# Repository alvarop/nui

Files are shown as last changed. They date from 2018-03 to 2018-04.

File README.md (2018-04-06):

# Nui

## Overview

Nui is an IR(evntually also BLE) controlled volume controller for analog audio. It sits between your audio source and speakers and can amplify or reduce the volume using IR commands (and evntually BLE).

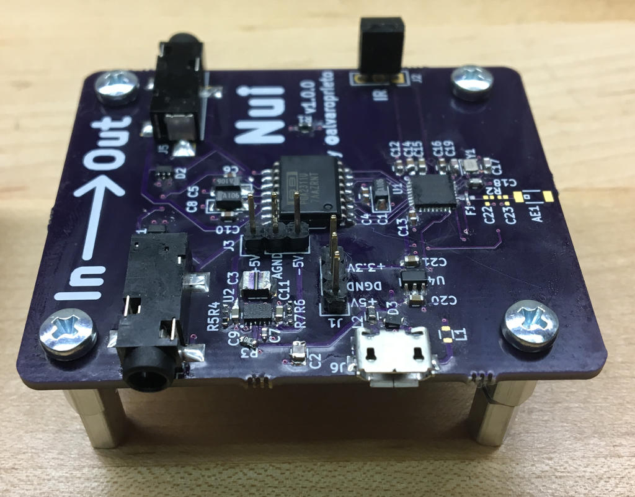
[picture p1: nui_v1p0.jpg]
Nui v1.0


Why do I need this, you may ask?

It all started because I have my trusty Logitech Z-2300 speakers and subwoofer I purchased back arond 2004/5. They still work great, but instead of being on my computer, they are used for my TV. Unfortunately, the TV's line out doesn't honor the TV's volume and is always outputting at max volume. Sure, I can get up and change the volume on the speakers themselves, but wouldn't it be more convenient to do it with the TV remote?!

That's how the Nui project started. It sits between my TV and my speakers and now I don't have to get up to change the volume :D

## Version 0.0.1 (Teensy version)

### Hardware
* The board files can be found [here](https://github.com/alvarop/nui/releases/tag/releases%2Fhw%2Fv0.0.1)

### Firmware
* The arduino/teensy code can be found [here](fw/teensy/nui.ino)

## Version 1.0.0 (NRF52 version)

### Hardware
* The board files can be found [here](hw/)

### Firmware
* The NRF52 code can be found [here](fw/nui/)

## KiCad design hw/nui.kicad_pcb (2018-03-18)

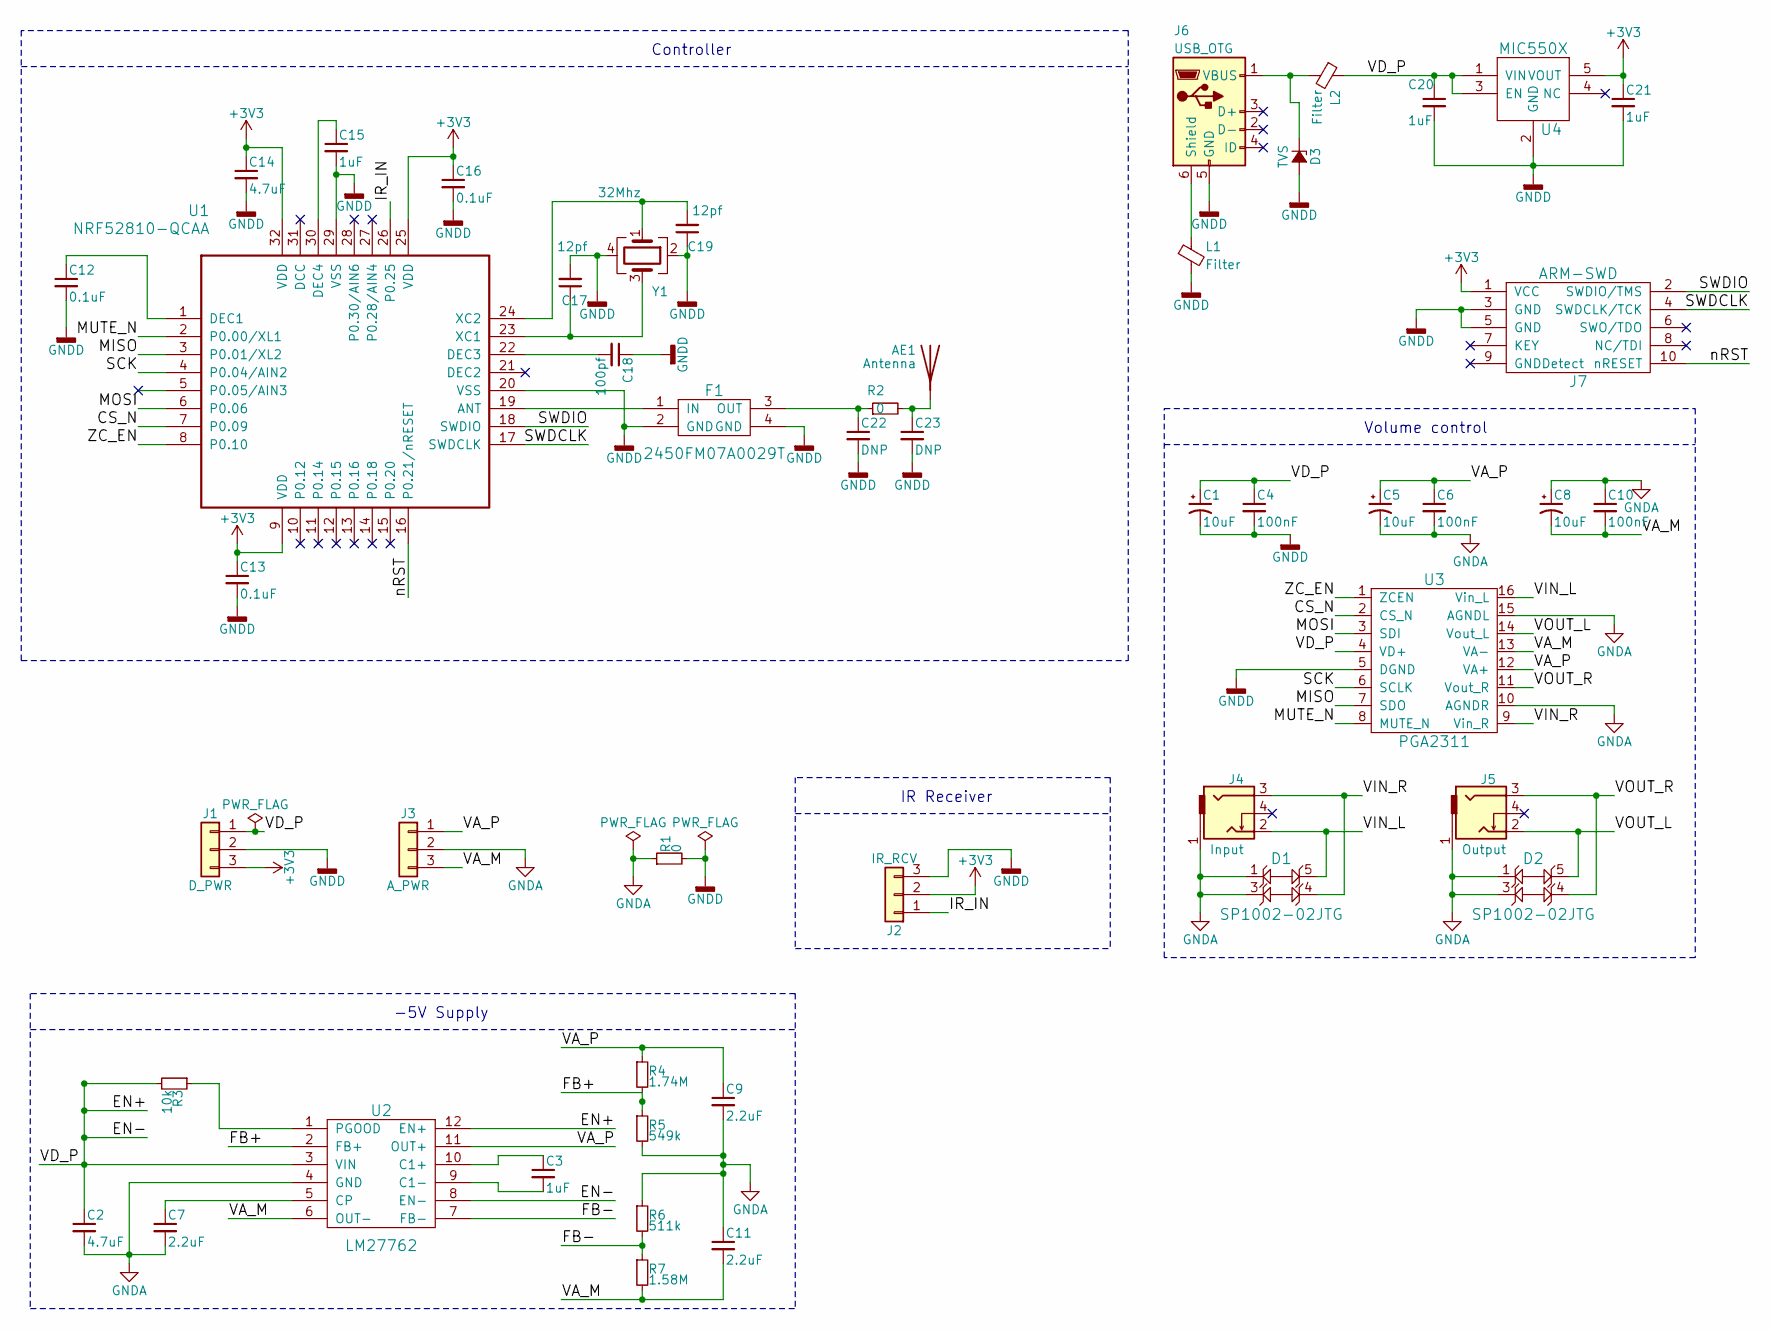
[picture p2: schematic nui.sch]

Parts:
AE1: Antenna; AMCA31-2R450G-S1F-T3
C1, C5, C8: 10uF; CP_Tantalum_Case-A_EIA-3216-18_Reflow; MPN F931A106MAA
C2: 4.7uF; C_0805; MPN LMK212BJ475KD-T
C3: 1uF; C_1210; MPN ECP-U1C105MA5
C4, C6, C10: 100nF; C_0603; MPN GRM188R71C104KA01D
C7: 2.2uF; C_0402_NoSilk; MPN JMK105BJ225MV-F
C9, C11: 2.2uF; C_0603; MPN C0603C225K8PACTU
C12, C13, C16: 0.1uF; C_0603
C14: 4.7uF; C_0603
C15, C20, C21: 1uF; C_0603
C17, C19: 12pf; C_0603
C18: 100pf; C_0603
C22, C23: DNP; C_0402_NoSilk
D1, D2: SP1002-02JTG; MPN SP1002-02JTG
D3: TVS; D_0603; MPN ESDA7P120-1U1M
F1: 2450FM07A0029T
J1: D_PWR; Pin_Header_Straight_1x03
J2: IR_RCV; Pin_Header_Straight_1x03; MPN TSOP2138
J3: A_PWR; Pin_Header_Straight_1x03
J4: Input; SJ-3524-SMT-TR; MPN SJ-3524-SMT-TR
J5: Output; SJ-3524-SMT-TR; MPN SJ-3524-SMT-TR
J6: USB_OTG; USB_MICRO_B
J7: ARM-SWD; ARM_SWD_SMD
L1, L2: Filter; R_0603; MPN BLM18KG221SZ1D
R1: 0; R_0603
R2: 0; R_0402_NoSilk
R3: 10k; R_0402_NoSilk; MPN CRCW040210K0JNEDC
R4: 1.74M; R_0402_NoSilk; MPN CRCW04021M74FKED
R5: 549k; R_0402_NoSilk; MPN CRCW0402549KFKED
R6: 511k; R_0402_NoSilk; MPN CRCW0402511KFKED
R7: 1.58M; R_0402_NoSilk; MPN CRCW04021M58FKED
U1: NRF52810-QCAA; NRF52810_QCAA_QFN32
U2: LM27762; MPN LM27762DSST
U3: PGA2311; PGA2311-SOIC; MPN PGA2311U
U4: MIC550X; SOT-23(M5)
Y1: 32Mhz; Crystal_SMD_2016-4pin_2.0x1.6mm

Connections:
+3V3: C13.1, C14.1, C16.1, C21.1, J1.3, J2.2, J7.1 (VCC), U1.9 (VDD), U1.25 (VDD), U1.32 (VDD), U4.5 (VOUT)
/CS_N: U1.7 (P0.09), U3.2 (CS_N)
/EN+: C1.1, C2.1, C4.1, C20.1, J1.1, L2.1, R3.2, U2.3 (VIN), U2.8 (EN-), U2.12 (EN+), U3.4 (VD+), U4.1 (VIN), U4.3 (EN)
/FB+: R4.2, R5.1, U2.2 (FB+)
/FB-: R6.2, R7.1, U2.7 (FB-)
/IR_IN: J2.1, U1.26 (P0.25)
/MISO: U1.3 (P0.01/XL2), U3.7 (SDO)
/MOSI: U1.6 (P0.06), U3.3 (SDI)
/MUTE_N: U1.2 (P0.00/XL1), U3.8 (MUTE_N)
/SCK: U1.4 (P0.04/AIN2), U3.6 (SCLK)
/SWDCLK: J7.4 (SWDCLK/TCK), U1.17 (SWDCLK)
/SWDIO: J7.2 (SWDIO/TMS), U1.18 (SWDIO)
/VA_M: C8.2, C10.2, C11.2, J3.3, R7.2, U2.6 (OUT-), U3.13 (VA-)
/VA_P: C5.1, C6.1, C9.1, J3.1, R4.1, U2.11 (OUT+), U3.12 (VA+)
/VIN_L: D1.5, J4.2, U3.16 (Vin_L)
/VIN_R: D1.4, J4.3, U3.9 (Vin_R)
/VOUT_L: D2.5, J5.2, U3.14 (Vout_L)
/VOUT_R: D2.4, J5.3, U3.11 (Vout_R)
/ZC_EN: U1.8 (P0.10), U3.1 (ZCEN)
/nRST: J7.10 (nRESET), U1.16 (P0.21/nRESET)
GNDA: C2.2, C5.2, C6.2, C7.2, C8.1, C9.2, C10.1, C11.1, D1.1, D1.3, D2.1, D2.3, J3.2, J4.1, J5.1, R1.1, R5.2, R6.1, U2.4 (GND), U3.10 (AGNDR), U3.15 (AGNDL)
GNDD: C1.2, C4.2, C12.2, C13.2, C14.2, C15.2, C16.2, C17.2, C18.1, C19.1, C20.2, C21.2, C22.2, C23.2, D3.2 (A), F1.2 (GND), F1.4 (GND), J1.2, J2.3, J6.5 (GND), J7.3 (GND), J7.5 (GND), L1.2, R1.2, U1.20 (VSS), U1.29 (VSS), U3.5 (DGND), U4.2 (GND), Y1.2, Y1.4
unnamed: AE1.1, C23.1, R2.2
unnamed: C3.1, U2.10 (C1+)
unnamed: C3.2, U2.9 (C1-)
unnamed: C7.1, U2.5 (CP)
unnamed: C12.1, U1.1 (DEC1)
unnamed: C15.1, U1.30 (DEC4)
unnamed: C17.1, U1.23 (XC1), Y1.3
unnamed: C18.2, U1.22 (DEC3)
unnamed: C19.2, U1.24 (XC2), Y1.1
unnamed: C22.1, F1.3 (OUT), R2.1
unnamed: D3.1 (K), J6.1 (VBUS), L2.2
unnamed: F1.1 (IN), U1.19 (ANT)
unnamed: J6.6 (Shield), L1.1
unnamed: R3.1, U2.1 (PGOOD)

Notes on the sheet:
Volume control
-5V Supply
Controller
IR Receiver

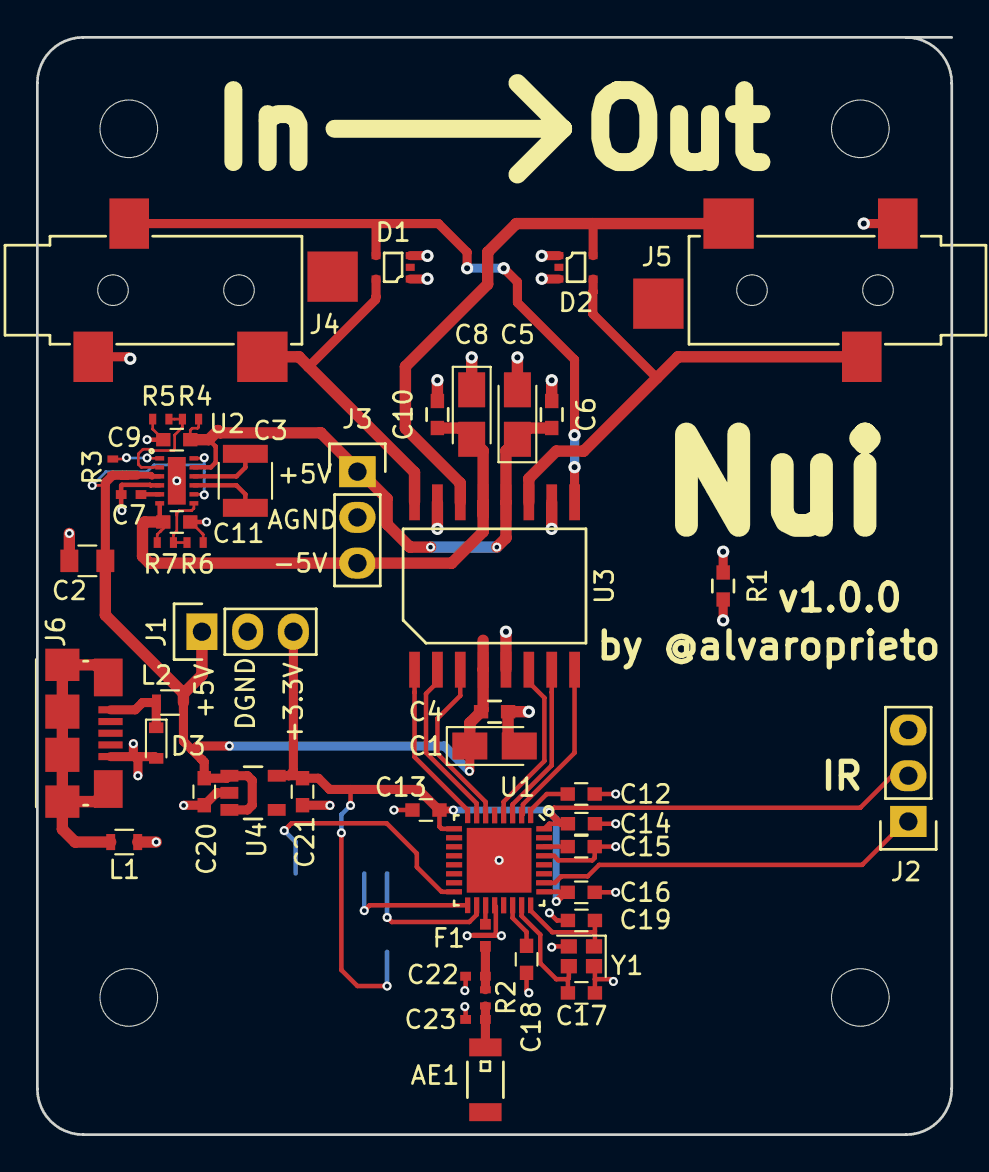
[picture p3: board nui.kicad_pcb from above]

Board: 2 copper layers, 50.8 x 61.0 mm, 49 parts (1 on the bottom side), 36 nets.

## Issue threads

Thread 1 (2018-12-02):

I have the same needs! Is this for sale?

trentrand, 2018-12-02:
Hey 👋

Great project! I attempted a similar solution by cracking open the speaker and replacing the potentiometer with an Arduino and a MCP41100 digital potentiometer.
The project produced horrible static and output quality; not sure why.

Anyways, this looks like a smarter solution which I'd love to have.

Do you have one for sale?

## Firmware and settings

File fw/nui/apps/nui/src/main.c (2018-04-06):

#include <assert.h>
#include <string.h>
#include <stdbool.h>

#include "sysinit/sysinit.h"
#include "console/console.h"
#include "os/os.h"
#include "bsp/bsp.h"
#include "hal/hal_gpio.h"
#include "hal/hal_timer.h"
#include "hal/hal_spi.h"

#include "nrfx.h"
#include "nrfx_spim.h"

#define NUI_TASK_PRI         (10)
#define NUI_STACK_SIZE       (256)
struct os_task nui_task;
os_stack_t nui_task_stack[NUI_STACK_SIZE];

typedef struct {
    uint32_t time;
    uint8_t value;
} edge_t;

static nrfx_spim_t spi_dev = NRFX_SPIM_INSTANCE(0);
static uint8_t current_volume = 164;
static bool mute = false;

// Maximum number of pulse edges to store
#define MAX_EDGES 128

// Timeout (in microseconds) before processing incoming data
#define TIMEOUT_US 11000

static edge_t edges[MAX_EDGES];
static uint16_t edge_index;

struct hal_timer ir_timeout_timer;

static struct os_mutex ir_processing_mutex;

static void ir_irq(void *arg) {
    os_error_t err;

    // If we're currently processing a packet, ignore incoming data
    // Not an issue now, but maybe once BLE is going it could cause problems
    err = os_mutex_pend(&ir_processing_mutex, 0);
    if(err == OS_OK) {
        // Store edge timestamp and current value
        edges[edge_index].time = hal_timer_read(1);
        edges[edge_index].value = hal_gpio_read(IR_IN_PIN);

        edge_index++;

        err = os_mutex_release(&ir_processing_mutex);
        assert(err == OS_OK);

        // Re-set ir timeout
        hal_timer_stop(&ir_timeout_timer);
        hal_timer_start(&ir_timeout_timer, TIMEOUT_US);
    }

}

// NEC Decoding state machine states
typedef enum {
    LEADING_PULSE,
    LEADING_SPACE,
    BIT_PULSE,
    BIT_SPACE,
} decode_state_t;

// Helper functions to determine if a pulse meets certain criteria
static inline bool is_leading_pulse(int32_t duration, uint8_t value) {
    return (value == 1 && duration > 8000 && duration < 10000);
}

static inline bool is_leading_space(int32_t duration, uint8_t value) {
    return (value == 0 && duration > 3500 && duration < 5500);
}

static inline bool is_bit_pulse(int32_t duration, uint8_t value) {
    return (value == 1 && duration > 400 && duration < 700);
}

static inline bool is_bit_space_0(int32_t duration, uint8_t value) {
    return (value == 0 && duration > 400 && duration < 700);
}

static inline bool is_bit_space_1(int32_t duration, uint8_t value) {
    return (value == 0 && duration > 1400 && duration < 1900);
}

// State machine to decode "NEC" IR encoded data
// See:
// http://techdocs.altium.com/display/FPGA/NEC+Infrared+Transmission+Protocol
uint16_t decode(uint32_t *result) {
    decode_state_t state = LEADING_PULSE;
    bool decoding = true;
    uint32_t index = 1;

    assert(result != NULL);

    *result = 0;

    while (decoding && index < edge_index) {
        int32_t duration = edges[index].time - edges[index - 1].time;
        uint8_t value = edges[index].value;
        switch(state) {
            case LEADING_PULSE: {
                if(is_leading_pulse(duration, value)) {
                    state = LEADING_SPACE;
                    index++;
                } else {
                    decoding = false;
                }
                break;
            }

            case LEADING_SPACE: {
                if(is_leading_space(duration, value)) {
                    state = BIT_PULSE;
                    index++;
                } else {
                    decoding = false;
                }
                break;
            }

            case BIT_PULSE: {
                if(is_bit_pulse(duration, value)) {
                    state = BIT_SPACE;
                    index++;
                } else {
                    decoding = false;
                }

                break;
            }

            case BIT_SPACE: {
                if(is_bit_space_0(duration, value)) {
                    (*result) <<= 1;
                    state = BIT_PULSE;
                    index++;
                } else if(is_bit_space_1(duration, value)) {
                    (*result) <<= 1;
                    (*result) |= 1;
                    state = BIT_PULSE;
                    index++;
                } else {
                    decoding=false;
                }

                break;
            }
        }
    }

    // Return the total number of edges (could be useful for repeat code, etc)
    return edge_index;
}

// These are the IR codes for the "AUX" setting on my particular Toshiba remote
typedef enum {
  AUX_VOL_DOWN = 0x4BB6C03F,
  AUX_VOL_UP = 0x4BB640BF,
  AUX_MUTE = 0x4BB6A05F
} commands_t;

void set_volume(uint8_t volume) {
    uint8_t vol[2] = {volume, volume};
    nrfx_spim_xfer_desc_t xfer = NRFX_SPIM_XFER_TX(&vol, sizeof(vol));
    hal_gpio_write(CS_N_PIN, 0);
    // hal_spi_txrx(0, vol, NULL, sizeof(vol));
    nrfx_spim_xfer(&spi_dev, &xfer, 0);
    hal_gpio_write(CS_N_PIN, 1);

    console_printf("volume %d\n", volume);
}

// Do something with the received data
static void process_ir_command(uint32_t command, uint16_t num_edges) {
    switch (command) {
        case AUX_VOL_DOWN: {
            console_printf("Volume down!\n");
            if (current_volume > 0) {
                current_volume--;
            }
            set_volume(current_volume);
            break;
        }
        case AUX_VOL_UP: {
            console_printf("Volume up!\n");
            if (current_volume < 255) {
                current_volume++;
            }
            set_volume(current_volume);
            break;
        }
        case AUX_MUTE: {
            console_printf("Mute!\n");
            mute = !mute;
            if(mute) {
                set_volume(0);
            } else {
                set_volume(current_volume);
            }
            break;
        }
        default: {
            // Do something with other codes?
            // console_printf("%08lX - %d\n", command, num_edges);
        }
    }
}

// Called to process data after not receiving IR edges for <TIMEOUT_US>
static void ir_timeout_cb(void *arg) {
    uint32_t result;
    uint16_t num_edges;
    os_error_t err;

    // Make sure we don't process more IR edges while we decode the packet
    err = os_mutex_pend(&ir_processing_mutex, 0xFFFFFFFF);
    assert(err == OS_OK);

    num_edges = decode(&result);

    // Reset edge index so we can receive the next packet!
    edge_index = 0;

    // Let the IR irq do it's thing again
    err = os_mutex_release(&ir_processing_mutex);
    assert(err == OS_OK);

    // Do something with the received data!
    process_ir_command(result, num_edges);
}

void nui_task_func(void *arg) {

    os_error_t err;

    // Use this mutex to make sure IR data isn't corrupted mid-decoding
    err = os_mutex_init(&ir_processing_mutex);
    assert(err == OS_OK);

    hal_gpio_irq_init(IR_IN_PIN, ir_irq, NULL,
        HAL_GPIO_TRIG_BOTH, HAL_GPIO_PULL_NONE);

    // Variable used to keep track of current pulse edge
    edge_index = 0;

    // 1MHz timer to measure incoming pulse edge times
    hal_timer_config(1, 1000000);

    // Timeout used to process a packet after some time without edges
    hal_timer_set_cb(1, &ir_timeout_timer, ir_timeout_cb, NULL);

    hal_gpio_irq_enable(IR_IN_PIN);

    hal_gpio_init_out(MUTE_N_PIN, 1);
    hal_gpio_init_out(SCK_PIN, 0);
    hal_gpio_init_out(MOSI_PIN, 0);
    hal_gpio_init_out(CS_N_PIN, 1);
    hal_gpio_init_out(ZC_EN_PIN, 1);

    nrfx_spim_config_t spi_config = NRFX_SPIM_DEFAULT_CONFIG;

    spi_config.sck_pin = SCK_PIN;
    spi_config.mosi_pin = MOSI_PIN;
    spi_config.miso_pin = MISO_PIN;

    // Workaround for NRFX_SPIM library bug.
    // If NRFX_SPIM_PIN_NOT_USED is used, the library takes it as 'pin 0'
    // and continues using it as a SS pin
    // Pin 2 is not connected on the 32-pin package
    spi_config.ss_pin = 2;

    uint32_t rval = nrfx_spim_init(&spi_dev, &spi_config, NULL, NULL);
    if (rval != NRFX_SUCCESS) {
        console_printf("spim_init error %08lX\n", rval);
    } else {
        console_printf("spim_init successfull\n");
    }

    // Set initial volume
    set_volume(current_volume);

    while (1) {
        os_time_delay(OS_TICKS_PER_SEC*100);
    }
}

int main(int argc, char **argv) {
    int rc;

    sysinit();

    os_task_init(
        &nui_task,
        "nui_task",
        nui_task_func,
        NULL,
        NUI_TASK_PRI,
        OS_WAIT_FOREVER,
        nui_task_stack,
        NUI_STACK_SIZE);

    while (1) {
        os_eventq_run(os_eventq_dflt_get());
    }
    assert(0);
    return rc;
}

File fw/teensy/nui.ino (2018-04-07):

#include <IRremote.h>
#include <SPI.h>  // include the SPI library:

// Set up all the pins!
int MUTE_PIN = 9;
int RECV_PIN = 21;
int CS_PIN = 10;
int ZC_EN = 8;
IRrecv irrecv(RECV_PIN);
decode_results results;

// Default volume (128/255)
uint8_t volume = 128;

// Mute is active low, so 1 is unmuted
uint8_t mute = 1;

void setup()
{
  Serial.begin(9600);
  irrecv.enableIRIn(); // Start the receiver
  Serial.println("Started");

  pinMode(MUTE_PIN, OUTPUT);
  digitalWrite(MUTE_PIN, 1);
  pinMode(CS_PIN, OUTPUT);
  digitalWrite(CS_PIN, HIGH);
  pinMode(ZC_EN, OUTPUT);
  digitalWrite(ZC_EN, 1);

  SPI.begin();
  SPI.setSCK(14);

  // Set initial volume
  Serial.printf("Volume: %d\n", volume);
  digitalWrite(CS_PIN, LOW);
  SPI.transfer(volume);
  SPI.transfer(volume);
  digitalWrite(CS_PIN, HIGH);
}

// IR Codes for my particular remote's "Aux" mode
typedef enum {
  AUX_VOL_DOWN = 0x4BB6C03F,
  AUX_VOL_UP = 0x4BB640BF,
  AUX_MUTE = 0x4BB6A05F
} commands_t;

void loop() {

  if (irrecv.decode(&results)) {

    switch (results.value) {
      case AUX_VOL_DOWN:
        {
          Serial.println("Volume Down!");
          if (volume > 0) {
            volume--;
          }
          break;
        }
      case AUX_VOL_UP:
        {
          Serial.println("Volume Up!");
          if (volume < 255) {
            volume++;
          }
          break;
        }
      case AUX_MUTE:
        {
          Serial.println("Mute!");
          mute ^= 1;
          digitalWrite(MUTE_PIN, mute);
          break;
        }
      default:
        {
          Serial.printf("Unknown command: 0x%08X\n", results.value);
        }

    }

    irrecv.resume(); // Receive the next value

    // Set the volume!
    Serial.printf("Volume: %d\n", volume);
    digitalWrite(CS_PIN, LOW);
    SPI.transfer(volume);
    SPI.transfer(volume);
    digitalWrite(CS_PIN, HIGH);
  }
}

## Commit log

2018-01-01 First draft of schematic done
    [nui.kicad_pcb, nui.sch]
2018-01-01 Footprints assigned and created
    [nui.sch]
2018-01-01 Layout almost done
    [nui.kicad_pcb, nui.sch]
2018-01-02 Layout done for v0.0.1
    [nui.kicad_pcb, nui.sch]
2018-01-26 Updating power supply circuit in NUI
    [nui.sch]
2018-01-26 Updated footprints and fixed swapped capacitors
    [nui.sch]
2018-01-27 Start updating pcb with new design
    [nui.kicad_pcb]
2018-01-27 Adding teensy fw
2018-03-18 Update Nui 1.0.0 to use nrf52810 and LM27762
    [nui.kicad_pcb, nui.sch]
2018-03-18 Got basic IR decoding with some bugs.
    It crashes when holding the volume button... TODO...
    [main.c]
2018-03-21 Major fw overhaul
    * Commented most of the things
    * No more blinky
    * Using 1MHz timer for data processing timeout
    * Protect IRQ/Decoding with mutex
    * Widened pulse timings to allow for error
    [main.c]
2018-04-04 Finally working on nui_v1p0! (IR Only)
    Requires modified apache-mynewt-core for nrf52810 support,
    currently located at:
    https://github.com/alvarop/mynewt-core/tree/nrf52810
2018-04-04 No longer need the #ifndef NRF52810 stuff on hal_i2c/spi.c
2018-04-05 Updated default volume and fixed SS bug
    [main.c]
2018-04-07 Add some comments to teensy code
